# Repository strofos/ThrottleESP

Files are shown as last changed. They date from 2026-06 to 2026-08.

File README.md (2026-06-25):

# Z21 Throttle ESP
Z21 throttle implementation on ESP32 like a light Z21 lok maus. You might even build it on ESP8266 as there is no ESP32 specific functions used. It uses a standard variable resistor (pot) to handle the speed. Only 126 DCC steps is implemented. A 3x4 keyboard is used to navigate throw the menu and handle the functions 0 to 9. The code gets data from the Z21 asyncronous, so if you change the locomotive or the tracks gets an EStop you get notified on the throttle also. 

# Electronic Components
 1. ESP32 DEV board
 2. Nokia 5110 PCD8544 display module
 3. 5k or 10k variable resistor
 4. 3x4 keyboard
 5. 18650 single cell as power suply
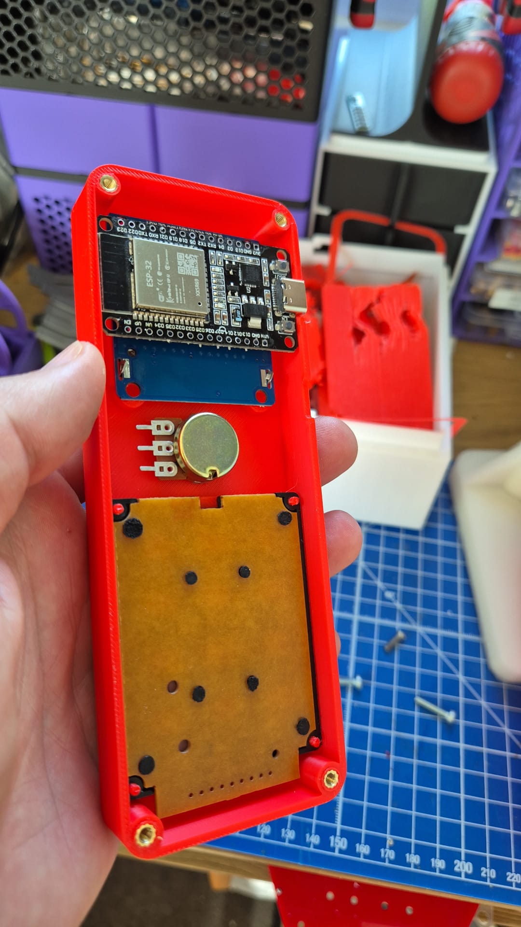
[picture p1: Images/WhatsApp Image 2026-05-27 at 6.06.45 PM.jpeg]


# Flash the code
Use a standard Arduino IDE to flash the code. Just make sure you have the correct board selected and install the graphic libraries from Adafruit. I used a Nokia 5110 display, PCD8544 chipset, SPI driven, so is easy to adapt it to another SPI display.  

# Setup the Wifi
The wifi SSID and password are set inside the Config.h file. Just edit it and put your own settings.

# TCP commands
The IP can be found in the menu of the throttle, goto Menu (hold * for 1 sec) and then select Wifi (press 2). The default port is 5983. The open Putty, add the IP and port and then select Telnet. If successful a command promt will apear. You can now send the desired command to the throttle.
Here is the complete list of commands implemented on the throttle:
- &lt;loco adr="45"> -> lock the loco address to 45. change the 45 to the desired address
- &lt;loco adr="*">  -> unlock the loco address menu. the address can be changed
- &lt;lock>          -> locks the maus, all actions are suspended
- &lt;unlock>        -> unlocks/frees the maus; also <loco> commands can be used

# How to make the enclosure
After you print the Top and Bottom enclosure parts on a standard 3D filament printer you need some M3 insert-threads and M3 standard screws to put it all together. See the images for more information. I test-printed them on my Anycubic Kobra S1 3D printer. The 18650 cell lid is still under design so it is missing from the current repo.

# Copyright
Fell free to download, make and share this project! A like or share of this repo will be much appreciated!

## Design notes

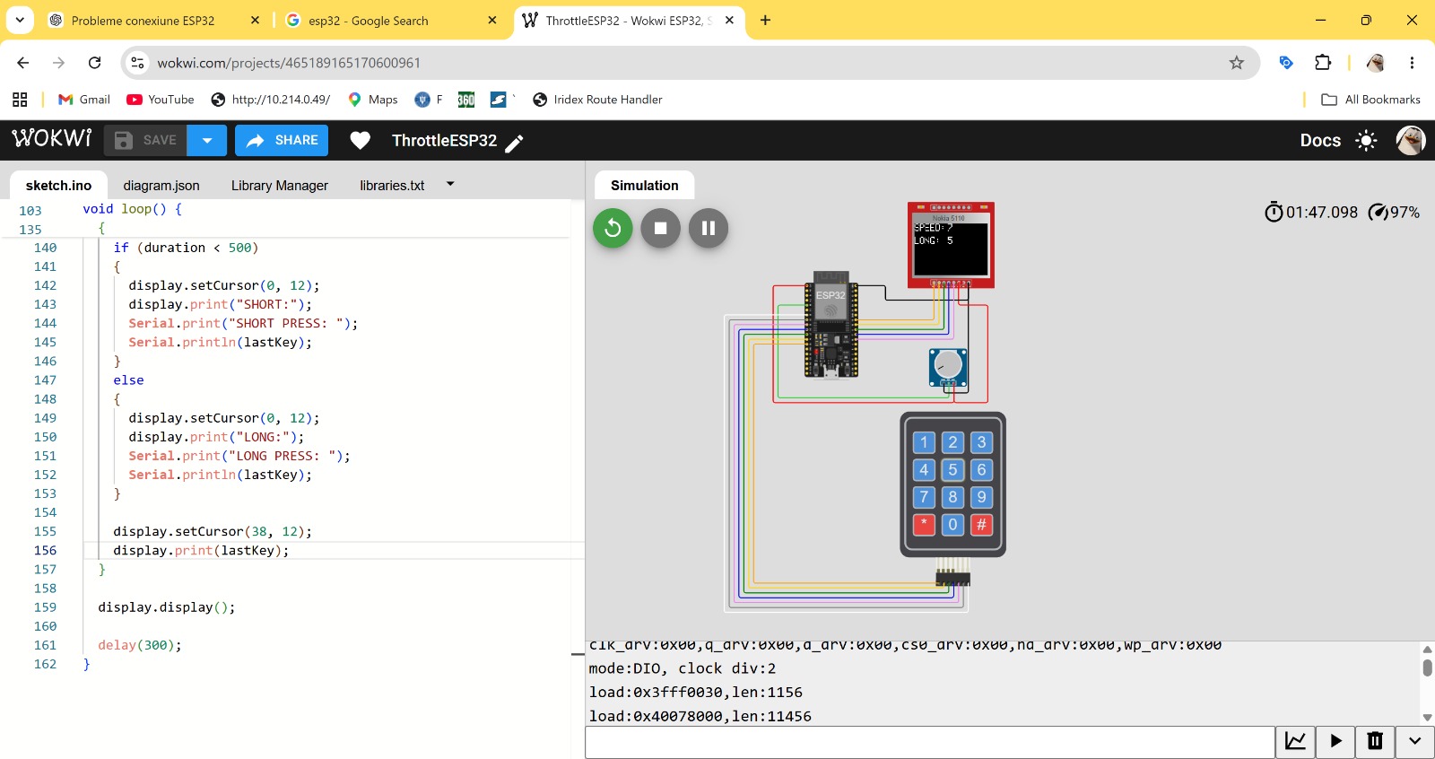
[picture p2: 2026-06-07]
Images/WhatsApp Image 2026-05-27 at 8.02.21 PM.jpeg

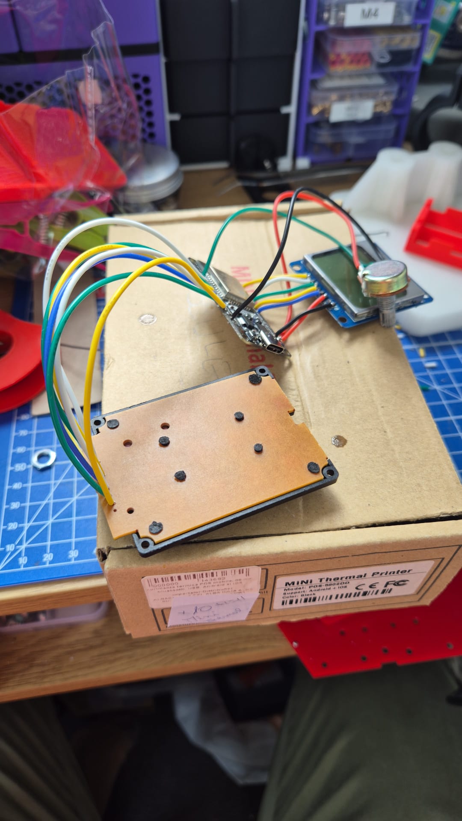
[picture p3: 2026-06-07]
Images/WhatsApp Image 2026-05-30 at 11.41.18 AM.jpeg

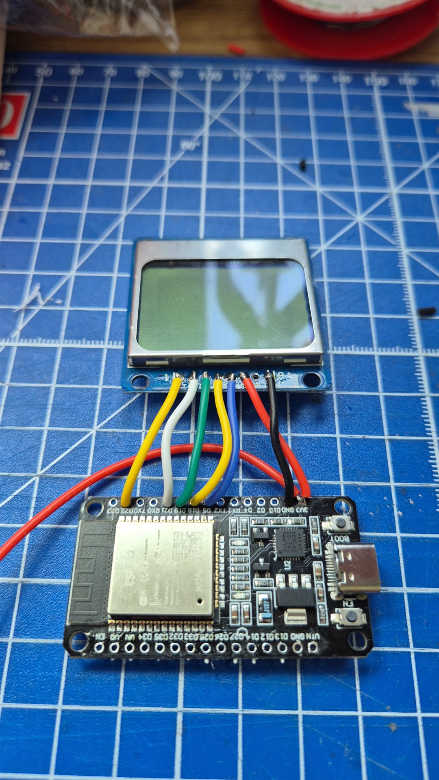
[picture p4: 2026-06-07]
Images/WhatsApp Image 2026-05-30 at 11.15.40 AM.jpeg

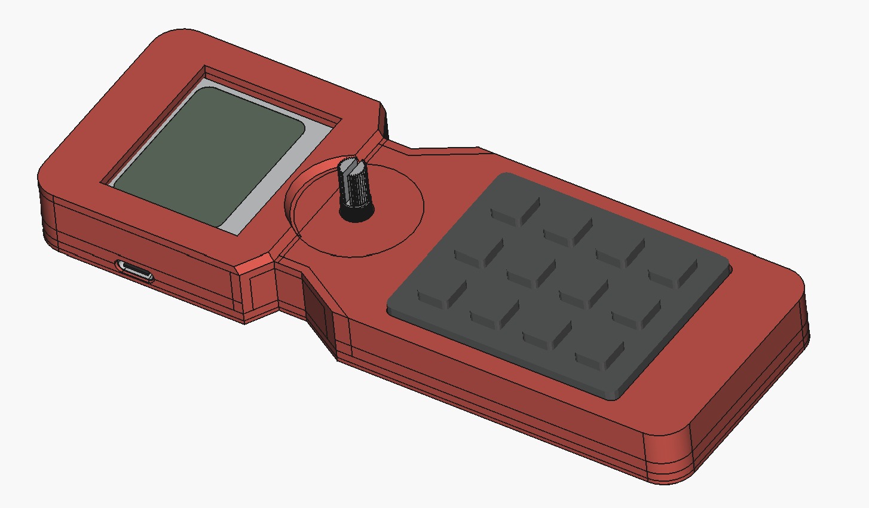
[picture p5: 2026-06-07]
Images/WhatsApp Image 2026-06-04 at 5.16.28 PM.jpeg

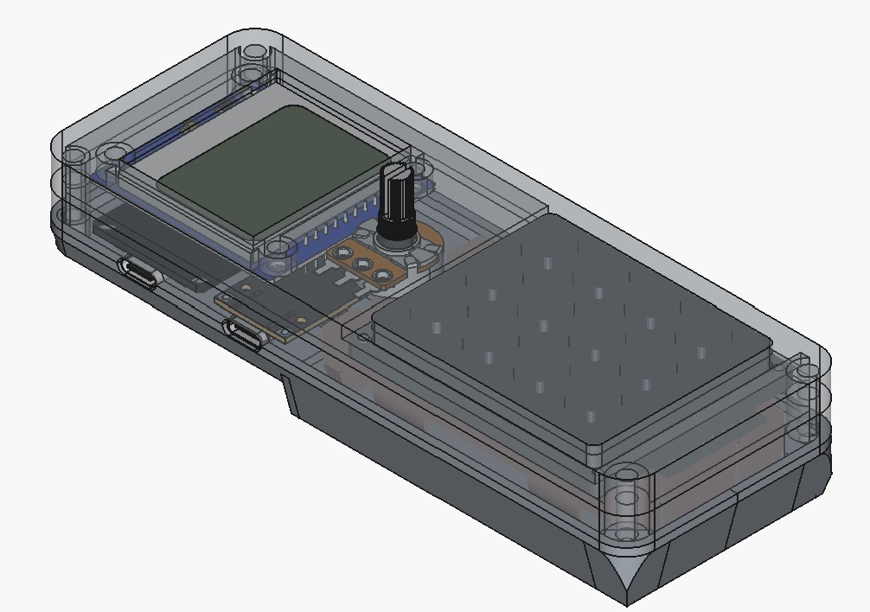
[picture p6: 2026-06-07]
Images/WhatsApp Image 2026-05-27 at 6.16.24 PM.jpeg

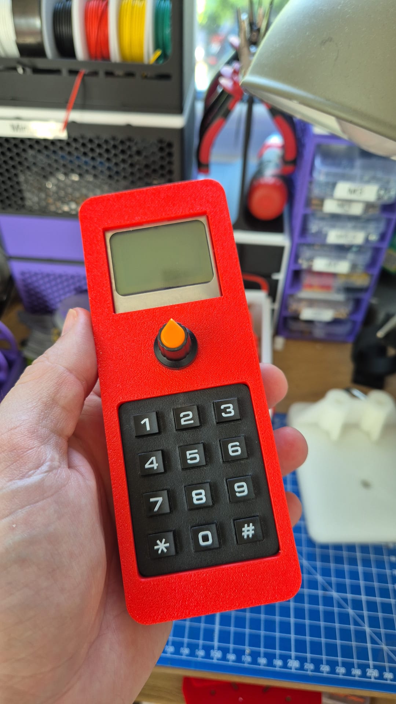
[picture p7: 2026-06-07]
Images/WhatsApp Image 2026-05-27 at 6.05.29 PM.jpeg

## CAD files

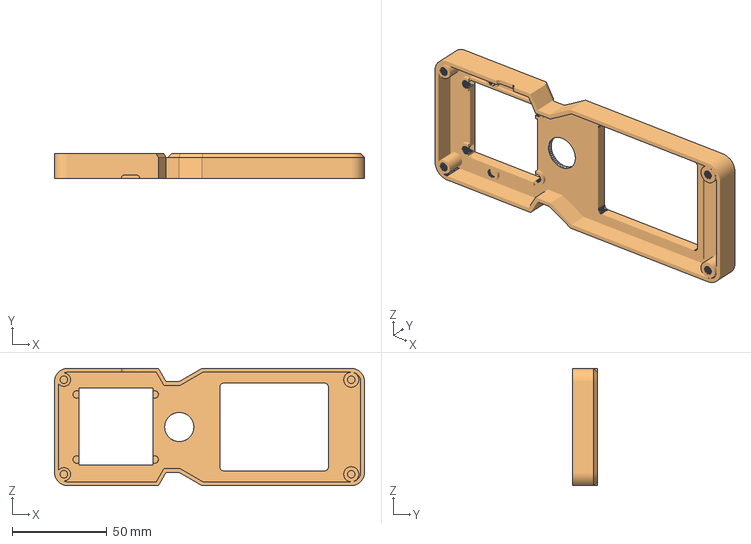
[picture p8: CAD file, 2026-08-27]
ThrottleESPEnclosure_v1.4.FCStd
164.0 x 13.0 x 62.0 mm
EnclosureTop
EnclosureTop (Meshed)

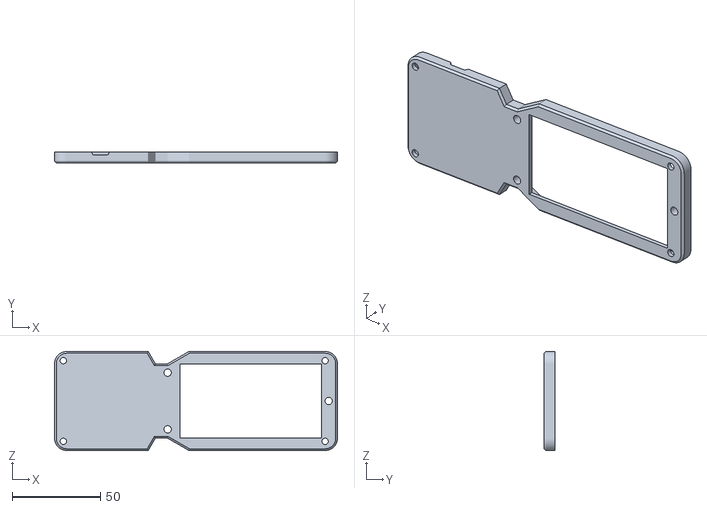
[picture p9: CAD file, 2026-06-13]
EnclosureBottom v1.03.stl
160.0 x 6.00 x 56.0

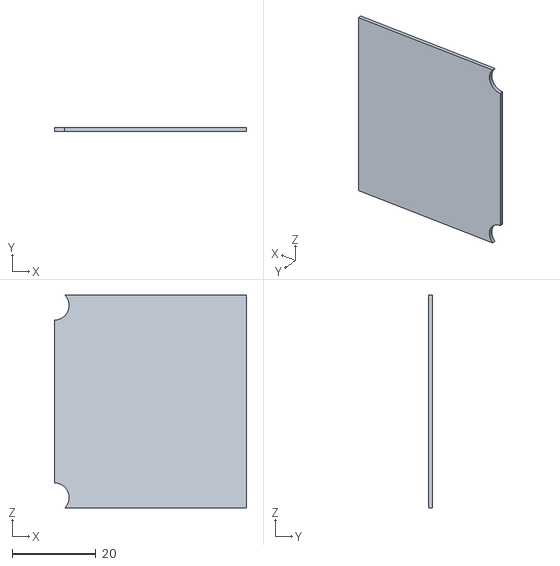
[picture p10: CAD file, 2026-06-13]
Distancer v1.02.stl
46.0 x 1.00 x 51.0

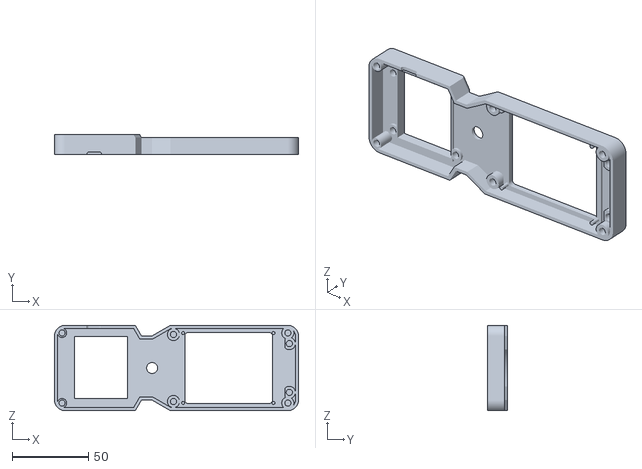
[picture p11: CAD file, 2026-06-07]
EnclosureTop v1.05.stl
160.0 x 13.0 x 56.0

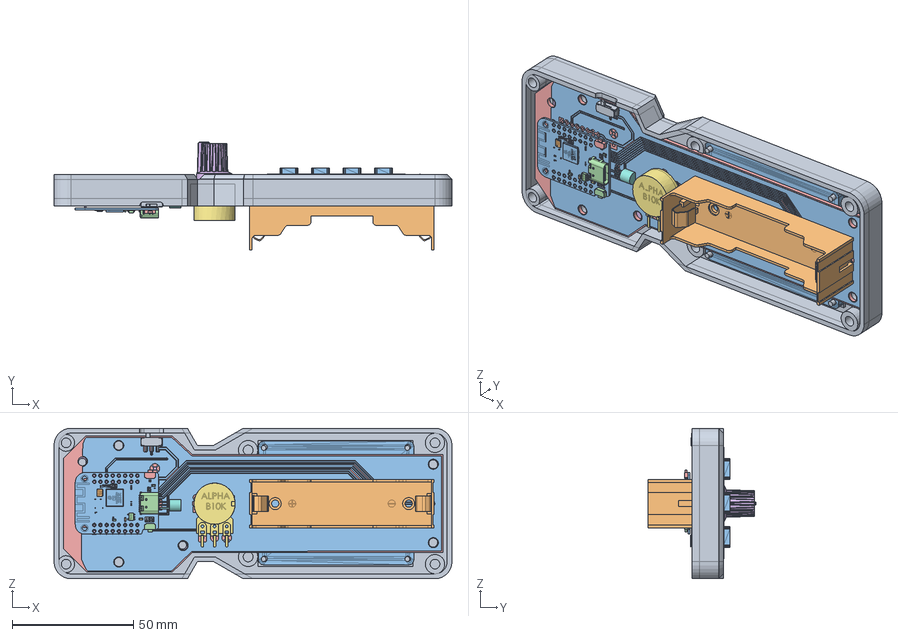
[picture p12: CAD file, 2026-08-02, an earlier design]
ThrottleESPEnclosure_v1.3.FCStd
164.0 x 44.4 x 62.0 mm
EnclosureTop
PinHeader_1x07_P2.54mm_Vertical
3x4_Keypad
R_1206_3216Metric
R_1206_3216Metric001
Nokia LCD
R_1206_3216Metric002
R_1206_3216Metric003
R_1206_3216Metric004
C_1210_3225Metric
C_1210_3225Metric001
USB_type_C_smd_12p v1
Pads
Pads2
Pads3
Pads4
Top Text
Bottom Text
Light
Anode Bottom
Cathode Bottom
Anode
Cathode
Base
40.00 MHz Oscillator v1
ESP32-S2 v3
ME6211-SOT23 v1
R01005 v2
R01005 v001
R01005 v002
R01005 v003
R01005 v004
R01005 v005
uController Reset Button v1
uController Reset Button v001
R_1206_3216Metric005
Potenciometro1
TO-92_Inline_Horizontal1
JS102011SAQN
Battery holderE18650
ThrottleAdapterBoard_copper
ThrottleAdapterBoard_via
ThrottleAdapterBoard_PCB
\X2\041f043e04420435043d04460438043e043c043504420440\X0\ \X2\042004430447043a0430\X0\

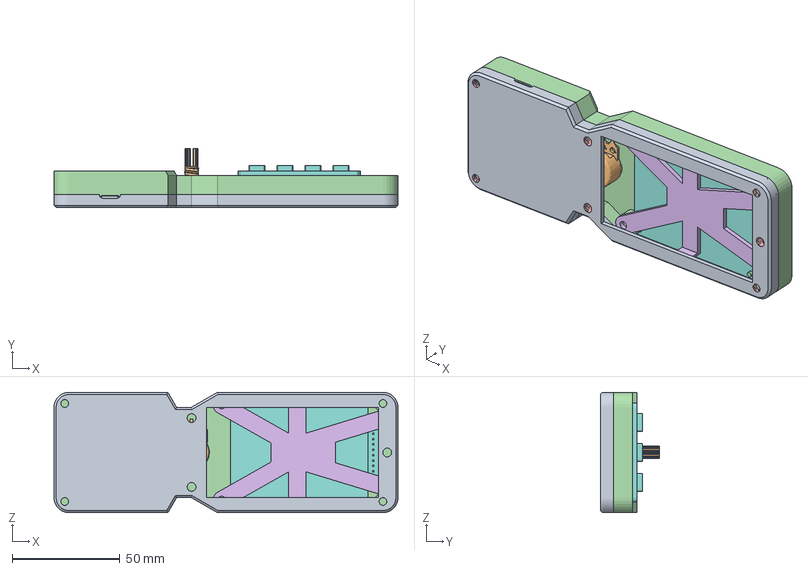
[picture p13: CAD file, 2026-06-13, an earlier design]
ThrottleESPEnclosure_v1.2.FCStd
160.0 x 27.5 x 56.0 mm
Potentiometer2
Nokia LCD
EnclosureTop
EnclosureBottom
KeyboardSupport
Distance
3x4 Keypad
EnclosureBottom (Meshed)

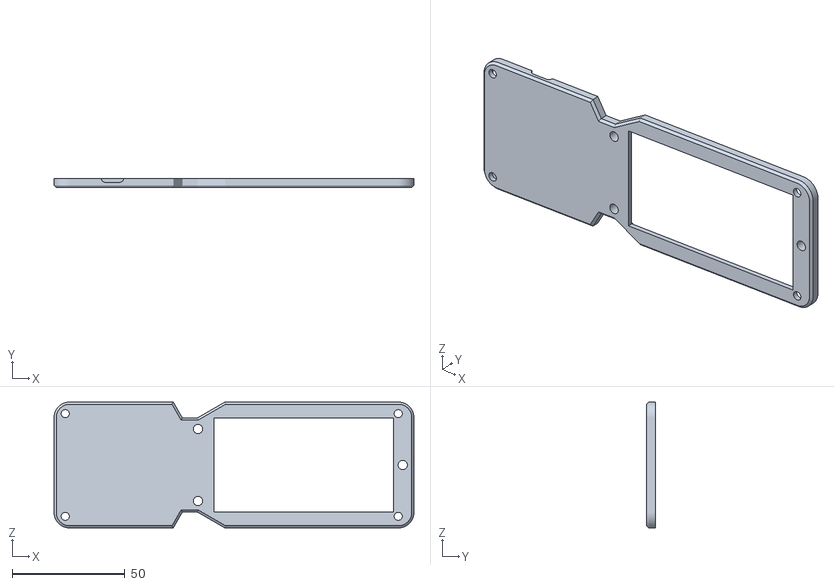
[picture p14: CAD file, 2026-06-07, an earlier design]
EnclosureBottom v1.02.stl
160.0 x 4.00 x 56.0

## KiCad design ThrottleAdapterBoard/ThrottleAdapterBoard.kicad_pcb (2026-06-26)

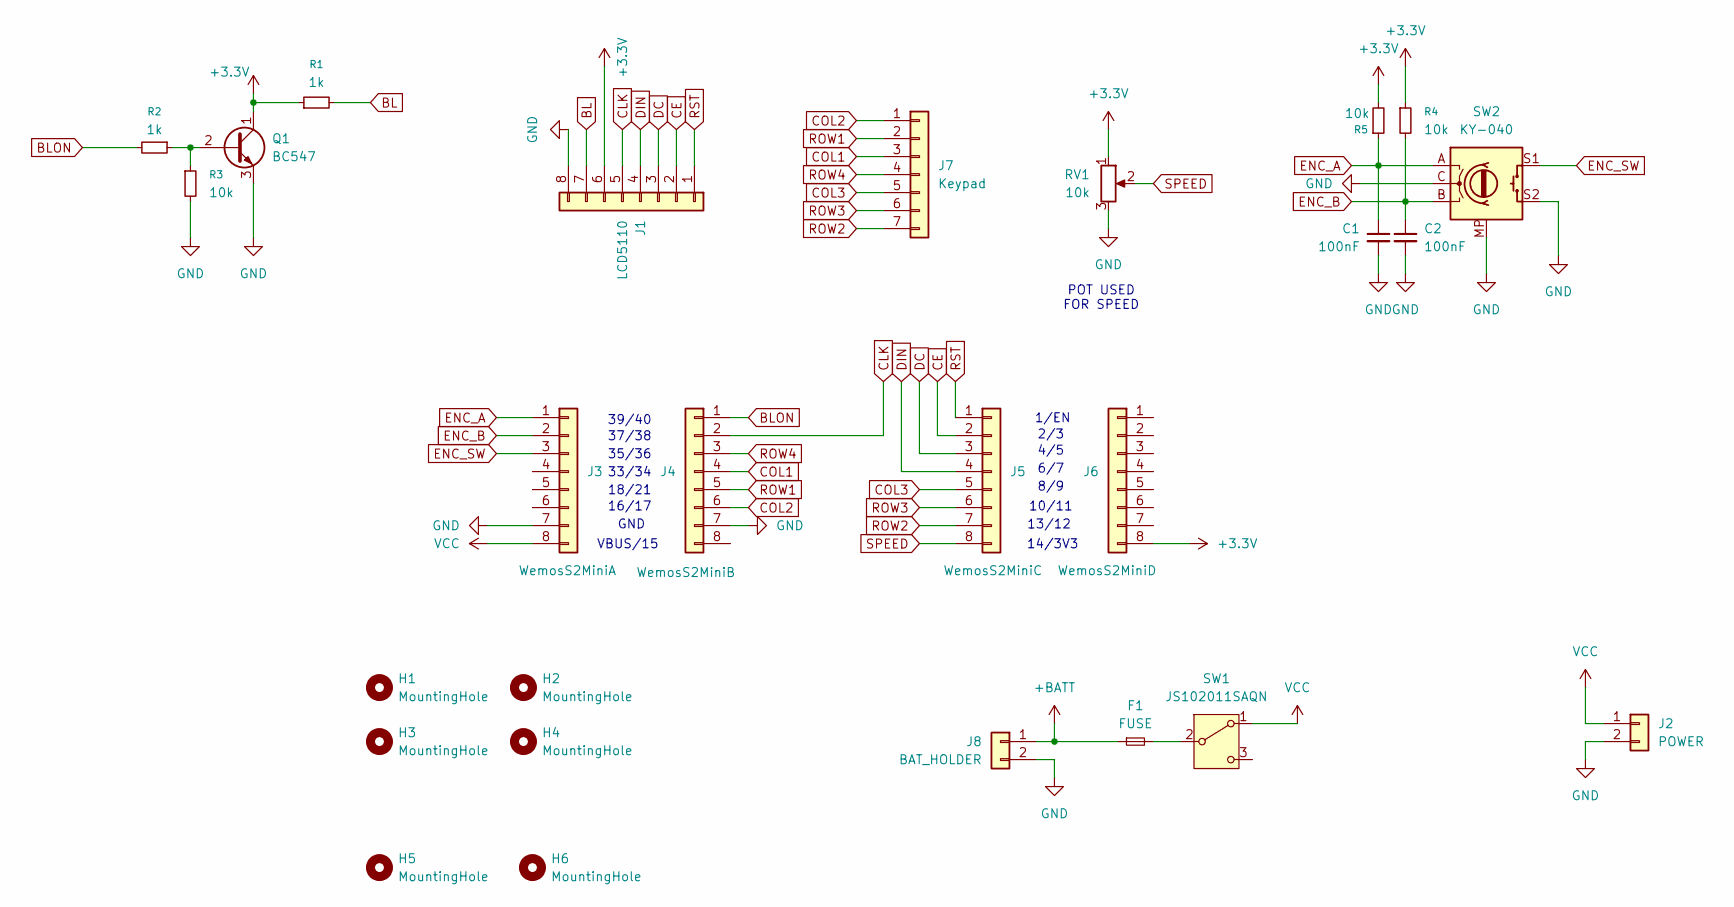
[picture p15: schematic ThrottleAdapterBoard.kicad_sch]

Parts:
C1, C2: 100nF; C_1210_3225Metric_Pad1.33x2.70mm_HandSolder
F1: FUSE; R_1206_3216Metric_Pad1.30x1.75mm_HandSolder
H1, H2, H3, H4, H5, H6: MountingHole; MountingHole_3.7mm
J1: LCD5110; PinHeader_1x08_P2.54mm_Vertical
J2: POWER; Altech_AK100_1x02_P5.00mm
J3: WemosS2MiniA; PinHeader_1x08_P2.54mm_Vertical
J4: WemosS2MiniB; PinHeader_1x08_P2.54mm_Vertical
J5: WemosS2MiniC; PinHeader_1x08_P2.54mm_Vertical
J6: WemosS2MiniD; PinHeader_1x08_P2.54mm_Vertical
J7: Keypad; PinHeader_1x07_P2.54mm_Vertical
J8: BAT_HOLDER; BatteryHolder_18650_THT
Q1: BC547; TO-92_Inline_Horizontal1
R1, R2: 1k; R_1206_3216Metric_Pad1.30x1.75mm_HandSolder
R3, R4, R5: 10k; R_1206_3216Metric_Pad1.30x1.75mm_HandSolder
RV1: 10k; Altech_AK100_1x03_P5.00mm
SW1: JS102011SAQN; SW_SPDT_CK_JS102011SAQN
SW2: KY-040; RotaryEncoder_Alps_EC12E-Switch_Vertical_H20mm_CircularMoun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

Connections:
+3.3V: J1.6, J6.8 (Pin_8_8), Q1.1 (C), R1.1, R4.1, R5.2, RV1.1
+BATT: F1.1, J8.1
BL: J1.7, R1.2
BLON: J4.1, R2.2
CE: J1.2, J5.2
CLK: J1.5, J4.2
COL1: J4.4, J7.3
COL2: J4.6, J7.1
COL3: J5.5, J7.5
DC: J1.3, J5.3
DIN: J1.4, J5.4
ENC_A: C1.1, J3.1, R5.1, SW2.A
ENC_B: C2.1, J3.2, R4.2, SW2.B
ENC_SW: J3.3, SW2.S1
GND: C1.2, C2.2, J1.8, J2.2, J3.7, J4.7, J8.2, Q1.3 (E), R3.2, RV1.3, SW2.C, SW2.MP, SW2.S2
unnamed: Q1.2 (B), R2.1, R3.1
unnamed: F1.2, SW1.2 (B)
ROW1: J4.5, J7.2
ROW2: J5.7, J7.7
ROW3: J5.6, J7.6
ROW4: J4.3, J7.4
RST: J1.1, J5.1
SPEED: J5.8, RV1.2
VCC: J2.1, J3.8, SW1.1 (A)

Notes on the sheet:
14/3V3
33/34
VBUS/15
10/11
4/5
16/17
GND
37/38
2/3
35/36
8/9
6/7
13/12
POT USED FOR SPEED
18/21
39/40
1/EN

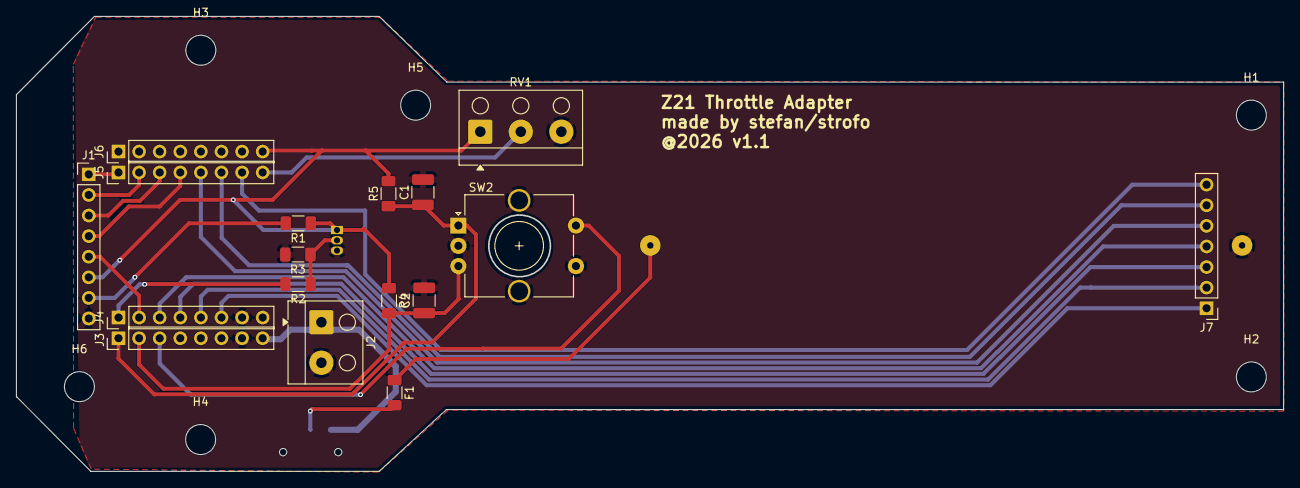
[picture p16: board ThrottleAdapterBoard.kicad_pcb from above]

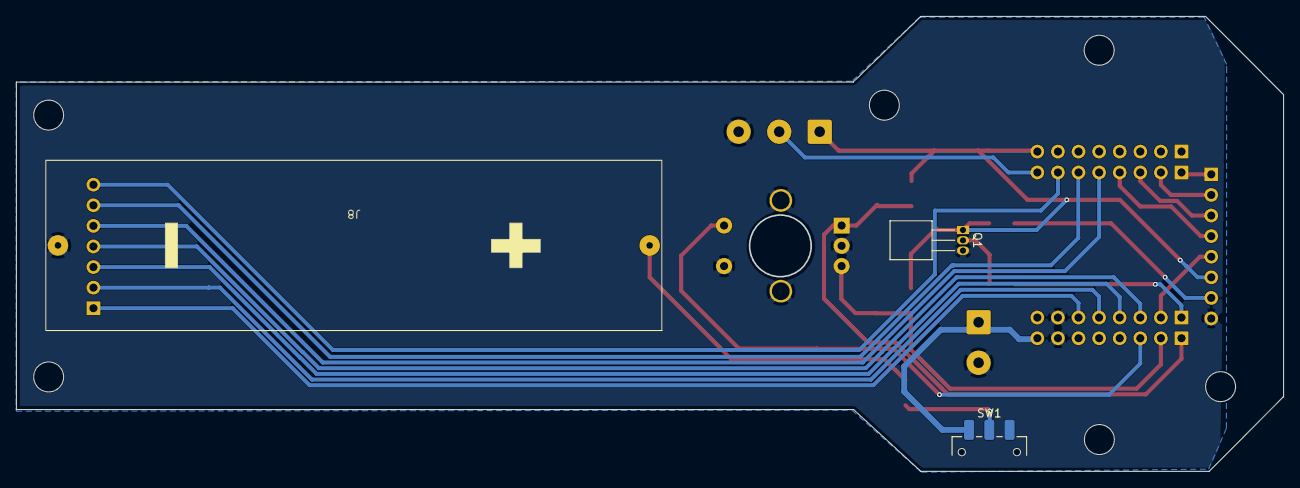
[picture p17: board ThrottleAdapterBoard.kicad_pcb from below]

Board: 2 copper layers, 156.3 x 56.1 mm, 26 parts (3 on the bottom side), 24 nets.

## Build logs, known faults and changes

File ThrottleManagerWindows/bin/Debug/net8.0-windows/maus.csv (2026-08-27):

IP | Culoare | Locomotiva | TimpStart | DeLaPornire
192.168.1.17 | ROSU | 47
192.168.1.20 | GRI | 4

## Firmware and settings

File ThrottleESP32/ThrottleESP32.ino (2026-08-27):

#include <WiFi.h>
#include <WiFiUdp.h>
#include "Config.h"
#include "Z21Protocol.h"
#include "UI.h"
#include "ThrottleWifi.h"
#include "TCPCommands.h"


// ---------------- SETUP ----------------
void setup()
{
  Serial.begin(115200);
  delay(300);

#ifdef ESP32_NODE
  Serial.println("ESP32_NODE Board");
#else 
  Serial.println("Mini S2 Board");
#endif

  //saveWifiConfig("UPCD22662E", "hTxwhrv3J4sc"); // initial wifi setup

  loadWifiConfig();

  startWifiConnect();

  setupTCPCommmands();

  setupUI();

  getStatus();

  //delay(300);

  //Serial.println("Setup done");
  //Serial.flush();
}

// ---------------- LOOP ----------------
unsigned long cmdCooloff = 0;
uint8_t cmdFunctionIndex = 0;
unsigned long cmdFunctionCooloff = 0;
unsigned long cmdLokoInfoCooloff = 0;
unsigned long cmdStatusInfoCooloff = 0;

void loop()
{
  if (!isUIUsingWifi()){ }

  checkWifiConnection();

  parseTCPCommands();

  extern bool throttleLocked;
  if (throttleLocked) {
    loopUILocked();
    return;
  }

  parseKeyPress();

  getZ21Commands();

  drawUI();

  // should set speed and functions
  extern uint16_t locoAddr;
  extern bool     locoLocked;
  extern uint8_t  locoSpeed;
  extern int8_t   locoDirection;
  extern volatile bool locoFunctionsStates[10];

  // async commands
  if (cmdCooloff < millis()) {
    cmdCooloff = millis() + 300;
    setSpeed(locoAddr, locoSpeed, locoDirection == LOK_FORWARD);
  }

  if (cmdFunctionCooloff < millis()) {
    setFunction(locoAddr, cmdFunctionIndex, locoFunctionsStates[cmdFunctionIndex]);
    cmdFunctionIndex++;
    if (cmdFunctionIndex >= 10) {
      cmdFunctionIndex = 0;
      cmdFunctionCooloff = millis() + 30000; // add a 30sec delay
    }
    else {
      cmdFunctionCooloff = millis() + 220;
    }
  }

  if (cmdLokoInfoCooloff < millis()) {
    getLocoInfo(locoAddr);
    cmdLokoInfoCooloff = millis() + 1030;
  }
  
  if (cmdStatusInfoCooloff < millis()) {
    getStatus();
    cmdStatusInfoCooloff = millis() + 1260;
  }

  //testSpeedSet();
  //testPowerOffOn();
  //getSystemInfo();
  //showUIKeysTest();
  // testUI();
  // return;
}

void testPowerOffOn() {
  if (trackPower == 0x01) {
    setTrackPowerOFF();
  }
  else {
    setTrackPowerON();
  }
}

void testSystemParams() {
  getSystemInfo();
}

void testSpeedSet()
{
  extern uint16_t locoAddr;
  extern uint8_t  locoSpeed;
  extern int8_t   locoDirection;

  // demo: creste viteza
  locoSpeed += 5;
  if (locoSpeed > 126) locoSpeed = 0;

  setSpeed(locoAddr, locoSpeed, locoDirection == LOK_FORWARD);

  // toggle lumina F0
  setFunction(locoAddr, 0, locoSpeed > 50);

  //getLocoInfo(locoAddr);

  //delay(500);
}

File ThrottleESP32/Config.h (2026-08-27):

#ifndef CONFIG_H
#define CONFIG_H
#include <WiFi.h>
#include <WiFiUdp.h>

//#define ESP32_NODE
#define ESP32_D1MINI_S2 

#ifdef ESP32_NODE
  #define LCD_RST   22
  #define LCD_CE    21
  #define LCD_DC    19
  #define LCD_DIN   18
  #define LCD_CLK    5
  #define POT_PIN   34
    
  // C2 R1 C1 R4 C3 R3 R2
  #define COL1      27
  #define COL2      12
  #define COL3      25
  #define ROW1      14
  #define ROW2      32
  #define ROW3      33
  #define ROW4      26
#else
  #define LCD_RST   1
  #define LCD_CE    2
  #define LCD_DC    4
  #define LCD_DIN   6
  #define LCD_CLK   38
  #define LCD_BL    40
  #define POT_PIN   14

  #define COL1      34
  #define COL2      17
  #define COL3       8
  #define ROW1      21
  #define ROW2      13
  #define ROW3      10
  #define ROW4      36
#endif




#define LOK_FORWARD  1
#define LOK_STOP     0
#define LOK_REVERSE -1

#define TRACK_OFF   0
#define TRACK_ON    1
#define TRACK_PROG  2
#define TRACK_ESTOP 3
#define TRACK_SHORT 8 

#define TCP_COMMANDS_PORT 8983
#define HTTP_COMMANDS_PORT 80

enum WifiState
{
  WIFI_IDLE,
  WIFI_RESET_1,
  WIFI_RESET_2,
  WIFI_RESET_3,
  WIFI_CONNECTING,
  WIFI_CONNECTED,
  WIFI_FAILED
};

extern WifiState wifiState;

#define AP_MODE_SSID "ESP32_CFRP"
#define AP_MODE_PASS "CFRPa55ing"

extern char ssid[33];
extern char password[65];

extern const IPAddress z21_ip;
extern const uint16_t z21_port;

extern WiFiUDP udp;

extern volatile uint8_t  trackPower;
extern bool     throttleLocked;
extern uint16_t locoAddr;
extern bool     locoLocked;
extern uint8_t  locoSpeed;
extern int8_t   locoDirection;
extern volatile bool locoFunctionsStates[10];

#endif

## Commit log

2026-06-07 Arduino code for ESP32
2026-06-07 Enclosure for the Throttle
    [ThrottleESPEnclosure_v1.2.FCStd]
2026-06-07 Enclosure design process
2026-06-07 Update README with detailed project information
    Expanded project description and added setup instructions, enclosure details, and copyright information.
2026-06-07 3D enclosure
    [EnclosureBottom v1.02.stl, EnclosureTop v1.05.stl]
2026-06-13 added wifi config functionalities. TCP commands for throttle lock is not working
    [Config.h, TCPCommands.cpp, ThrottleESP32.ino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]
2026-06-13 added a distancing part
    [Distancer v1.02.stl, ThrottleESPEnclosure_v1.2.FCStd]
2026-06-13 Document TCP commands for throttle control
    Added TCP commands section with command list for throttle.
2026-06-13 Create EnclosureBottom v1.03.stl
    [EnclosureBottom v1.03.stl]
2026-06-25 kicad board
    [ThrottleAdapterBoard.kicad_pcb, ThrottleAdapterBoard.kicad_sch]
2026-06-26 PCB Board
    [ThrottleAdapterBoard.kicad_pcb, ThrottleAdapterBoard.kicad_sch]
2026-08-02 Debug Build
    [maus.csv]
2026-08-02 Eclosure 1.3
    [ThrottleESPEnclosure_v1.3.FCStd]
2026-08-27 support for D1 Mini Esp32 S2
2026-08-27 Windows Working Exe
    [maus.csv]
2026-08-27 An updated enclosure
    [ThrottleESPEnclosure_v1.4.FCStd]
2026-08-28 throttle manager android
